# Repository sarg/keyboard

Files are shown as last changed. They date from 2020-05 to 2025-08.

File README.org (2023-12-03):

My journey to this keyboard began with a birthday gift. I got a Microsoft Sculpt Comfort keyboard and finally learned the proper 10 finger typing method. Then I got into spacemacs and fell in love with the idea of using space as a leader key. And as a newly adopted emacs user I began using Ctrl and Alt heavily. Reaching for control required unnatural wrist movement and I got to know that the solution is to remap Caps as Ctrl. I was living with this hack for a while until I learned a better idea - to remap LCtrl with LAlt. That's when I started looking for the keyboards with shorter space, so that LCtrl is easily reachable by the left thumb. Eventually I stumbled upon a world of DIY keyboards and started dreaming about ergodox. It was too pricey and had not the ideal layout so I decided to build my own keeb.
I had a rough understanding of what I'm aiming for - a handwired split keyboard with a orthogonal layout and a thumb cluster where I could leave hands on the home row indefinetely. So I started by ordering the parts - switches and caps.
When the switches came I immediately started to design a layout for my keyboard which fits my hands the perfectly.

* Parts

| Name                |   Qty | Price, $ |
|---------------------+-------+----------|
| Diodes 1n4148       |   100 |     0.78 |
| Keys Gateron Brown  |    50 |    21.00 |
| Keys Gateron Red    |    10 |          |
| Keys Gateron Other  |     5 |          |
| Keycaps PBT DSA     |    65 |    17.90 |
| Atmega32u4          |     1 |     2.88 |
| Atmega32u4          |     1 |     3.22 |
| Wires               | 1 set |      2.2 |
| 3.5mm plug          |     2 |      0.9 |
| 3.5mm cable         |     1 |     1.58 |
| encoder             |     5 |     1.78 |
| knob                |    10 |     1.40 |
| petg filament 1kg   |     1 |       30 |
| petg leftover       |       |      -24 |
| soldering paste     |     1 |     2.29 |
| soldering wire 100g |     1 |       11 |
| soldering wire left |       |      -10 |
|---------------------+-------+----------|
| tent screws         |     8 |          |
| plastidip           |     1 |          |
| tent fixing nuts    |     4 |          |
| tent nuts M5        |     4 |          |
|---------------------+-------+----------|
| total               |       |    62.93 |
#+TBLFM: @>$3=vsum(@I..@II)

* Layout
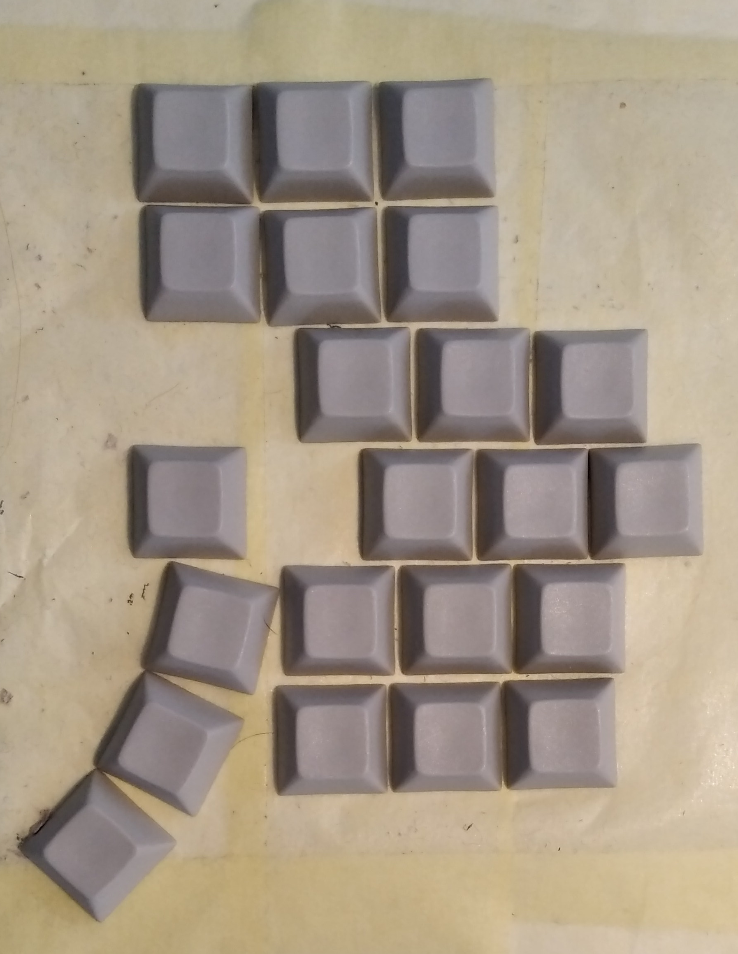
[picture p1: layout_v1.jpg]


- To find a best layout for my hands I've put several stripes of masking tape glue side up on a sheet of paper.
- Then I've adjusted columns to my liking and measured the offsets.
- I have Gateron switches which are Cherry-MX compatible. So the hole size is 14x14 mm and distance between holes should be 5 mm.
- Thumb cluster is parameterized in polar coordinates.

* Case design
** v1
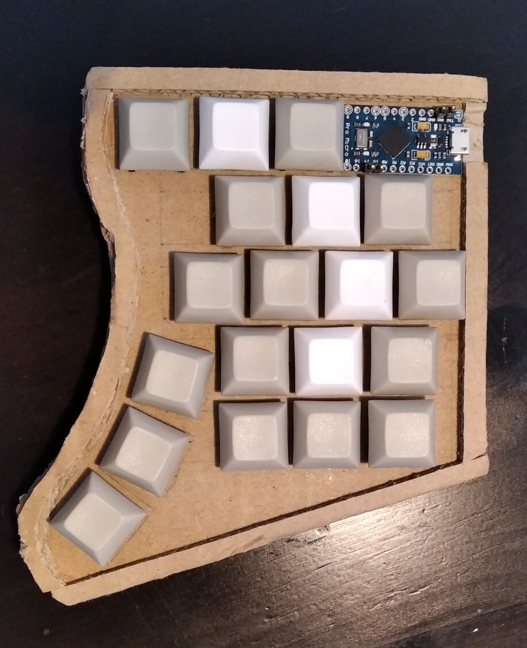
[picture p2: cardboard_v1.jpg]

** v2
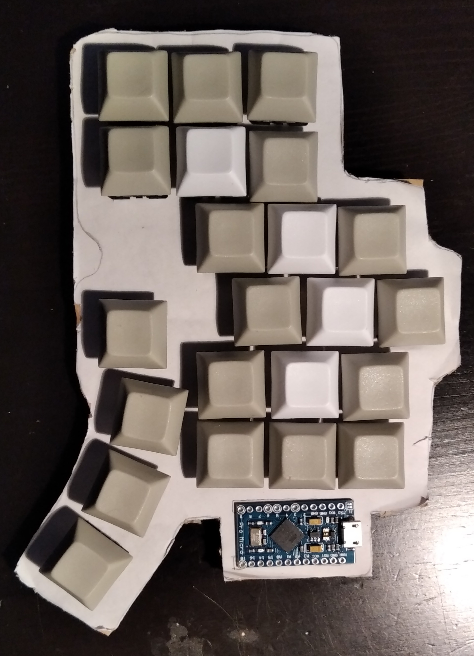
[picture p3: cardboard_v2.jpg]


** manufacturing
I'm going to choose one of the options.
1. PCB only
   jlcpcb, x5 ~ 27$ + 11$ shipping
2. *3d printed*
3. laser cutted
   price estimation:
   - $5.14 x 2 + $9 (fixed, handling) = $19.28 (ponoko)
   - €8.20 x 2 + shipping (formulor.de), no 1.5mm material

3d printing it is. Next time I'll try PCBs. It seems that you can use PCB as top plate and the manufacturer could mill holes of any shape.
* 3d printing
https://thomasbaart.nl/2019/04/07/cheat-sheet-custom-keyboard-mounting-styles/

- [[https://all3dp.com/1/3d-printing-support-structures/][need of support structures for overhang]]
- tolerances for an easy assembly
- choosing proper thickness to ensure integrity

Requirements.
1. switch should be firmly attached to the keyboard
   switch is designed to be mounted on a panel 1.5 mm thick and soldered onto PCB
   you can select one of those options - pcb+panel, panel only, pcb only

   produces: mounting place

2. switch should be positioned under the finger and easily accessible without much finger movement
   there are few ergonomic layouts that minimize finger movement. Just take one and adapt it to your hands

   2.1 keycaps are wider than the switch body. there should be minimal distance between keycaps so that they don't touch
   ortholinear + thumb cluster shaped as an arc

   produces: layout

3. mounting plate should be sturdy enough to not bend when typing

   produces: plate thickness

4. switches should be wired to the controller
   pcb or handwiring. Both need some vertical space
   something that elevates the plate needs to be implemented:
   - pins
   - another plate

   produces: wiring space

5. controller should have some place

   produces: controller location

6. underside of the keyboard should be protected
   pcb or handwiring should be protected from water spills and mechanical damage

   produces: bottom plate

7. optional: halves of a split keyboard should communicate

   produces: cable between halves, connectors

9. optional: tilt/tent

   produces: tent brackets

from handbook of 3d printing
make wall thickness proportional to nozzle width
add fillets everywhere
<45 degree overhang doesn't require support

** first print
For first print I've prepare a single row of 5 keys where each hole has size $14+i*0.1, i in [-2..2]$. I've found 14-0.2 the best. Then I've prepared small test case where I've mounted all the different types of switches I have. I had to redesign promicro mount after the print as the board wasn't fitting nicely.

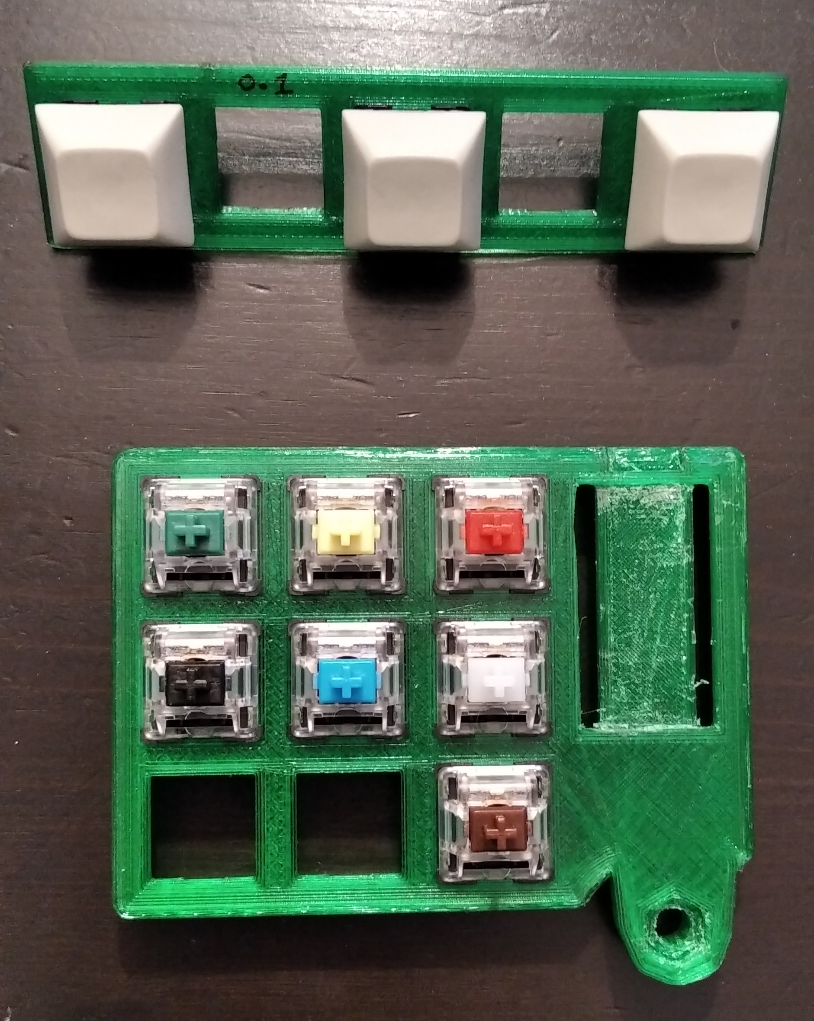
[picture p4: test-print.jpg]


* Hand-wiring
[[https://deskthority.net/viewtopic.php?f=7&t=6050&start=][BrownFox step by step - deskthority]]

The keyboard has 23 keys per hand - 3 rows of 6 columns and the fourth row of 4 thumb keys and an encoder button. It fits in a 4x6 matrix and requires =4+6=10= pins. Encoder takes 2 pins and serial connection takes another 1. In total: 10 pins for keys + 2 for encoder + 1 for serial + GND + VCC = 15 pins.

Some pins has extra functions and they have to be used last.

* Firmware
Consult [[https://beta.docs.qmk.fm/developing-qmk/c-development/hardware_keyboard_guidelines][documentation]].

Create new template with =./util/new_keyboard.sh=

#+BEGIN_SRC sh :dir firmware :results output :exports both
tree --noreport
#+END_SRC

#+RESULTS:
#+begin_example
.
|-- config.h
|-- keymaps
|   `-- default
|       |-- config.h
|       |-- keymap.c
|       `-- readme.md
|-- rules.mk
|-- sarg.c
`-- sarg.h
#+end_example

Let's go file by file to find minimal set of tweaks:

** =config.h=
#+BEGIN_SRC c
#define MATRIX_ROWS 8
#define MATRIX_COLS 6
/*
quantum/split_common/matrix.c presumes that kbd is split evenly by rows

#define ROWS_PER_HAND (MATRIX_ROWS / 2)
*/

// pinout http://i.imgur.com/wMNx2u6.png
#define MATRIX_ROW_PINS { D0, D5 }
#define MATRIX_COL_PINS { F1, F0, B0 }

#define DIODE_DIRECTION COL2ROW

#define SOFT_SERIAL_PIN D0  // or D1, D2, D3, E6
#+END_SRC

** =info.json=
Can be skipped, used in QMK web configurator.
** =rules.mk=
#+BEGIN_EXAMPLE
BOOTLOADER = caterina
SPLIT_KEYBOARD = yes
#+END_EXAMPLE
** =sarg.c=
Could be left as is.
** =sarg.h=
Here you define a macro that returns array of arrays with your layout.
#+INCLUDE: "./firmware/sarg.h" :lines "21-45" src c
** =keymaps/default/keymap.c=
Define layout in =keymaps= array.

* First compilation.
#+BEGIN_SRC sh
bin/qmk compile -kb sarg -km default
#+END_SRC

#+BEGIN_EXAMPLE
...
Checking file size of sarg_default.hex                                                              [OK]
 * The firmware size is fine - 23964/28672 (83%, 4708 bytes free)
#+END_EXAMPLE

* TODO link

Nicinabox has a [very nice and detailed guide](https://github.com/nicinabox/lets-split-guide) for the Let's Split keyboard, that covers most everything you need to know, including troubleshooting information.
* GUIX
#+BEGIN_SRC sh
guix time-machine -C channels.scm -- environment --pure -m manifest.scm
python3 -m venv pyvenv
source pyvenv/bin/activate
pip3 install -U qmk

make firmware
make flash
#+END_SRC
* flashing qmk-dfu
 1. build avrisp2 firmware from [[https://github.com/abcminiuser/lufa/tree/7a3b523c6473f9f6e0a7696f8ce66ee76119b21c/Projects/AVRISP-MKII][lufa]]
    #+begin_src sh
make -C Projects/AVRISP-MKII/ MCU=atmega32u4 BOARD=LEONARDO F_CPU=16000000
    #+end_src
 2. Flash avrisp2 firmware on promicro using avrdude
    #+begin_src sh
 while read i; do if [ "$i" = ttyACM0 ]; then break; fi; done \
    < <(inotifywait  -e create,open --format '%f' --quiet /dev --monitor)

 echo "Found device... flashing"
 avrdude  -patmega32u4 -c avr109 -P/dev/ttyACM0 -U flash:w:$1:i
    #+end_src
   #+begin_src sh
    sh flash.sh Projects/AVRISP-MKII/AVRISP-MKII.hex
   #+end_src
 3. Solder 6 wires for ISP programming
    #+begin_example
[ProMicro as AVRISP-mkII] <==> [Target ProMicro (or other AVR)]
GND <--> GND
VCC <--> VCC
PF4 <--> RST
PB1 <--> PB1 (SCK)
PB3 <--> PB3 (MISO)
PB2 <--> PB2 (MOSI)
    #+end_example
 4. Flash QMK firmware with bootloader (production)
    #+begin_src sh
 avrdude -p atmega32u4 -c avrisp2 -v -e -U lfuse:w:0x5E:m -U hfuse:w:0x99:m -U efuse:w:0xF3:m
 avrdude -p atmega32u4 -c avrisp2 -v -e -U flash:w:sarg_default_production.hex
    #+end_src
    Fuses are not magical. These basically set clock source, bootloader size and
    enable some features of the chip. Sure the values should be chosen carefully, for that consult the official datasheet for the controller. See also:
    https://rfong.github.io/rflog/2021/09/29/avr/
    https://docs.qmk.fm/#/isp_flashing_guide?id=flashing-the-bootloader
    https://www.engbedded.com/fusecalc/
 5. Repeat for the second ProMicro. Now that it has the dfu programmer, flash it this way
    #+begin_src
 dfu-programmer atmega32u4 erase
 dfu-programmer atmega32u4 flash AVRISP-MKII.hex
    #+end_src
 6. From now on to flash the keyboard, press the QK_BOOT key (see layout) and it will reboot to bootloader.

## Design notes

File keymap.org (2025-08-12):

* base
** left
#+name: l0
| ESC  | Q   | W         | E         | R         | T           |
| TAB  | A   | LALT_T(S) | LCTL_T(D) | LSFT_T(F) | G           |
| MINS | Z   | X         | C         | V         | B           |
| XXX  | ENT | MYCM      | LALT      | MO(1)     | LGUI_T(ENT) |
** right
#+name: r0
| Y           | U         | I         | O         | P    | BSPC |
| H           | RSFT_T(J) | RCTL_T(K) | RALT_T(L) | SCLN | QUOT |
| N           | M         | COMM      | DOT       | SLSH | BSLS |
| RALT_T(SPC) | MO(2)     | RALT      | RGUI      | ENT  | XXX  |
** encoders
#+name: e0
| PGUP | PGDN  |
| UP   | DOWN  |
* digits
** left
#+name: l1
| GRV | 1       |  2 | 3     | 4    |  5 |
|     |         |    | PGUP  | PGDN |    |
| F1  | F2      | F3 | F4    | F5   | F6 |
| XXX | QK_BOOT |    | TO(3) |      |    |
** right
#+name: r1
| 6    | 7    | 8  | 9    | 0    | MINS |
| LEFT | DOWN | UP | RGHT |      |      |
| F7   | F8   | F9 | F10  | F11  | F12  |
| RSFT | LGUI |    |      | MPLY | XXX  |
** encoders
#+name: e1
| VOLD | VOLU |
| VOLD | VOLU |
* symbols
** left
#+name: l2
| TILD | EXLM | AT | HASH | DLR | PERC |
|      |      |    |      |     |      |
|      |      |    |      |     |      |
| XXX  |      |    |      |     | LSFT |
** right
#+name: r2
| CIRC | AMPR | LPRN | RPRN | ASTR |     |
| MINS | EQL  | LBRC | RBRC |      |     |
| UNDS | PLUS | LCBR | RCBR |      |     |
|      |      |      |      |      | XXX |
** encoders
#+name: e2
| MEDIA_PREV_TRACK | MEDIA_NEXT_TRACK |
| UP               | DOWN             |
* gaming
** left
#+name: l3
| ESC   | 7 | 8    | 1    |    2 |   3 |
| GRV   | 9 | LEFT | UP   | RGHT |   4 |
| TO(0) | 0 | Q    | DOWN |    6 |   5 |
| XXX   |   | ENT  | TRNS |    C | SPC |
** right
#+name: r3
|   |   |   |   |   |     |
|   |   |   |   |   |     |
|   |   |   |   |   |     |
|   |   |   |   |   | XXX |
** encoders
#+name: e3
|   |   |
|   |   |
* keymap.json
#+name: helper
#+begin_src elisp :results none
(defun qmk/keyname (k)
  (let* ((m (and (stringp k)
                 (s-match (rx (group (+? anychar)) "("
                              (group (+ anychar) ")"))
                          k)))
         (fn (and m (nth 1 m)))
         (arg (and m (nth 2 m)))
         (fn-as-is (member fn '("MO" "TO"))))

    (cond
     ((numberp k) (format "KC_%d" k))
     ((string-empty-p k) "KC_NO")
     ((string-equal "XXX" k) nil)
     (fn-as-is k)
     (fn (concat fn "(KC_" arg))
     ((s-match "^.._" k) k)
     (t (concat "KC_" k)))))
#+end_src

#+name: layer
#+begin_src elisp :var l=l0 :var r=r0
(->>
 (-zip-with #'append l r)
 (-flatten)
 (-map #'qmk/keyname)
 (-filter #'identity)
 (-map (lambda (k) (format "%S" k)))
 (s-join ",\n"))
#+end_src

#+name: encoder
#+begin_src elisp :var e=e0
(s-join
 ", "
 (-map
  (lambda (enc)
    (apply #'format "{\"ccw\": %S, \"cw\": %S}"
           (-map #'qmk/keyname enc)))
  e))
#+end_src

#+begin_src js :tangle firmware/keymaps/default/keymap.json :noweb yes
{
  "version": 1,
  "notes": "",
  "documentation": "generated by org-mode",
  "author": "",
  "keyboard": "emajesty/eiri",
  "keymap": "keymap",
  "layout": "LAYOUT",
  "encoders": [
      [<<encoder(e0)>>],
      [<<encoder(e1)>>],
      [<<encoder(e2)>>],
      [<<encoder(e3)>>]
  ],
  "layers": [
    [
      <<layer(l0,r0)>>
    ],
    [
      <<layer(l1,r1)>>
    ],
    [
      <<layer(l2,r2)>>
    ],
    [
      <<layer(l3,r3)>>
    ]
  ]
}
#+end_src

#+name: cencoder
#+begin_src elisp :var e=e0 :var l=0
(s-join
 ",\n"
 (-map-indexed
  (lambda (idx enc)
    (format "{ %d, %d, false, %s, NO },\n{ %d, %d, true, %s, NO }"
            l idx (qmk/keyname (nth 0 enc))
            l idx (qmk/keyname (nth 1 enc))))
  e))
#+end_src

#+name: clayer
#+begin_src elisp :var l=l0 :var r=r0 :var i=0
(concat
(s-join ",\n"
        (-filter #'identity
        (-flatten
         (-map-indexed
          (lambda (row keys)
            (-map-indexed
             (lambda (col key)
               (when-let ((skey (qmk/keyname key)))
                  (format "{ %d, %d, %d, %s, NO }" i row col skey)))
             keys))
          (append l (-map #'reverse r)))))))
#+end_src

#+begin_src c :tangle write_eeprom/keymap.h :noweb yes
const KEY keys[] = {
  <<clayer(l0, r0, 0)>>,
  <<clayer(l1, r1, 1)>>,
  <<clayer(l2, r2, 2)>>,
  <<clayer(l3, r3, 3)>>
};

const ENCODER encoders[] = {
  <<cencoder(e0, 0)>>,
  <<cencoder(e1, 1)>>,
  <<cencoder(e2, 2)>>,
  <<cencoder(e3, 3)>>
};
#+end_src

# Local Variables:
# compile-command: "just eeprom"
# End:

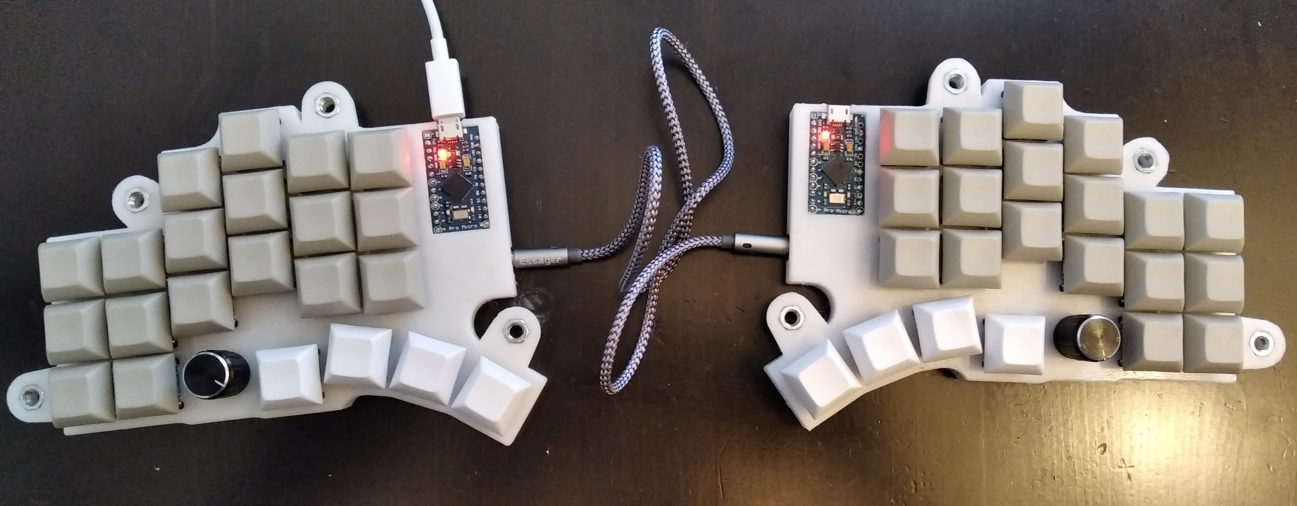
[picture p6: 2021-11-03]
photos/keyb.jpg

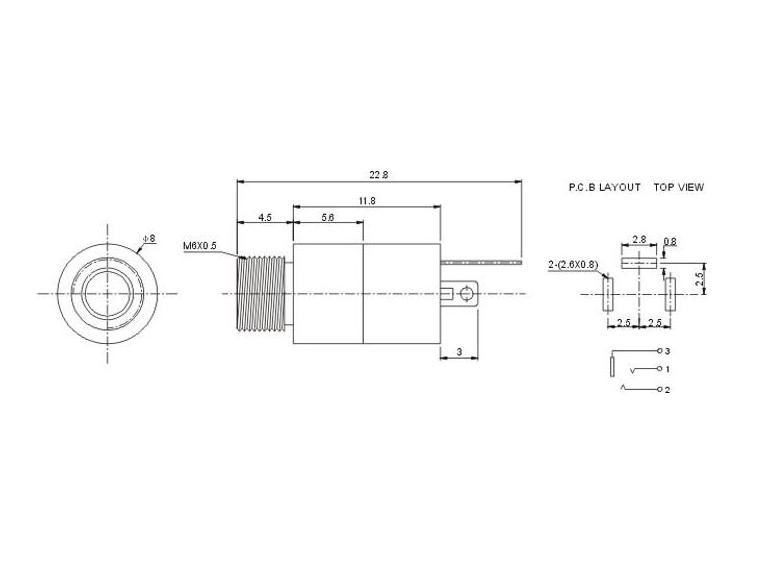
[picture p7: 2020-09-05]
pj392.jpg

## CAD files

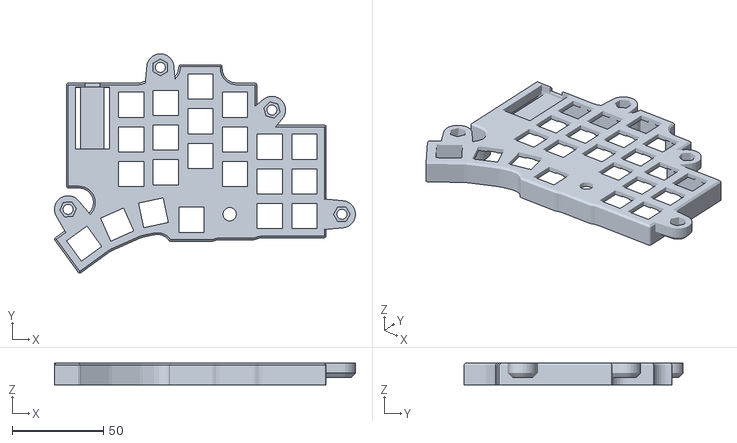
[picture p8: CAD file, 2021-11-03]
right.stl
165.0 x 120.3 x 12.0

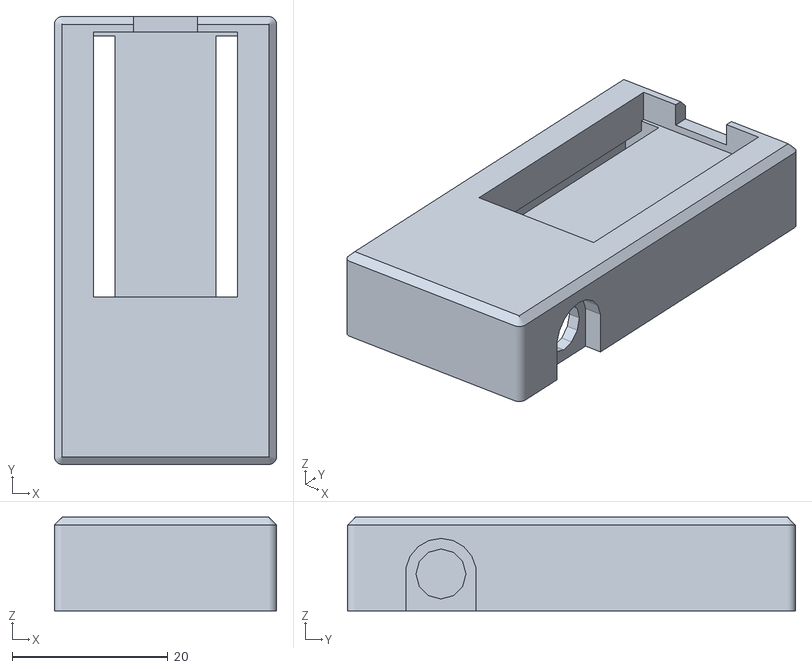
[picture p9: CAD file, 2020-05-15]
test-ic.stl
28.5 x 57.5 x 12.0

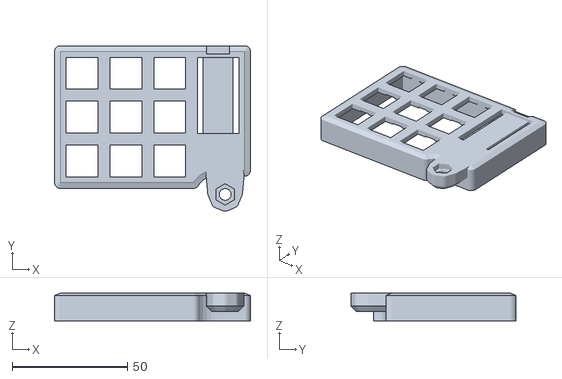
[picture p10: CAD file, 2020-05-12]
test-keyb.stl
84.9 x 71.7 x 12.0

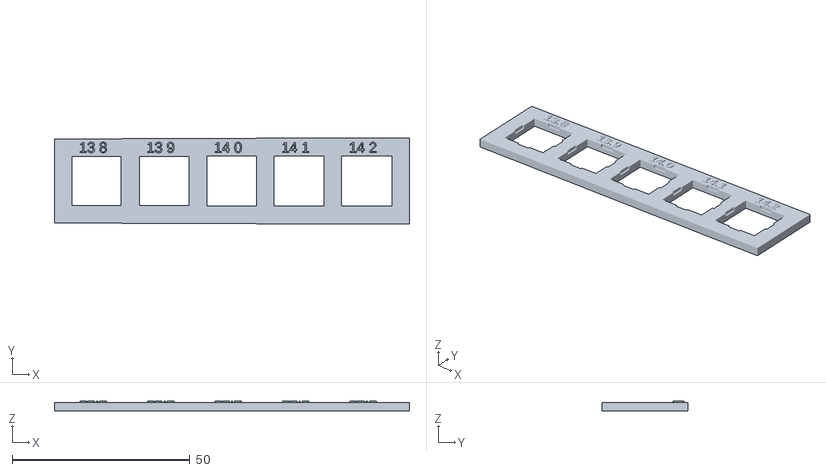
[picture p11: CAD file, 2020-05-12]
calibrate.stl
100.0 x 24.2 x 2.90

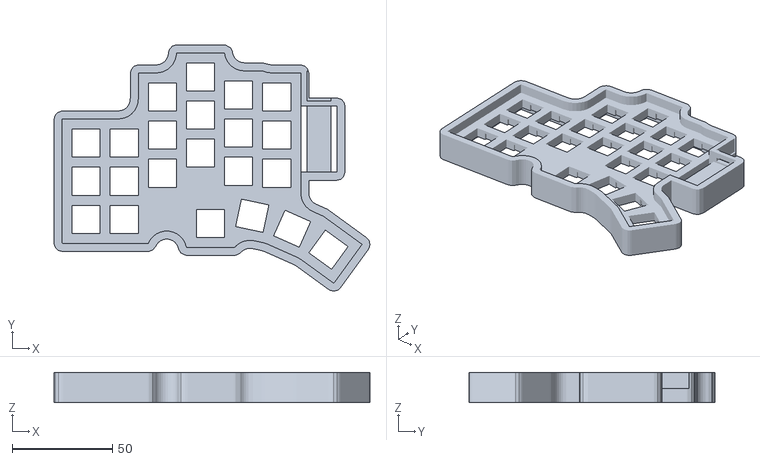
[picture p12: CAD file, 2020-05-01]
keyb.stl
157.5 x 122.8 x 15.0

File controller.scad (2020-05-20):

ic_thickness = 1;
ic_size=[18,33];

usb_socket_height=2;
trrs_d=8;
trrs_w=10;

trrs_pos=[0, -ic_size[1]/2-trrs_d/2-trrs_w/2,(thickness+deepening)/2-0.5];

function get_ic_size() = ic_size;

module board() {
    square(size=ic_size, center=true);
}

module trrs_socket() {
    translate(trrs_pos) {
        translate([ic_size[0]/2+wall_thickness,0,0]) {
            rotate([0,90,0]) cylinder(h=4.5,d=6, $fn=50);

            translate([wall_thickness,0,0])
                rotate([0,90,0]) cylinder(h=2,d=8, $fn=50);

            translate([-11.8,0,0]) rotate([0,90,0])
                cylinder(h=11.8,d=8, $fn=50);

            translate([-11.8-3,0])
                cube([3,2,1]);
        }
    }
}

module controller_perimeter() {
    union() {
        offset(delta=2) board();
        offset(delta=2)
        translate(trrs_pos)
            square([ic_size[0], trrs_w], center=true);
    }
}

module cutout() {
    union() {
        // submerge controller in the plate
        translate([0,0,thickness-ic_thickness])
            linear_extrude(height=ic_thickness+1)
            board();

        // space for IC pins
        linear_extrude(height=thickness)
            difference() {
                board();
                square(size=ic_size-[2.6*2, 0], center=true);
            }
    }
}

module promicro() {
    translate([0,0,-ic_thickness])
        linear_extrude(height=ic_thickness)
        board();

    translate([-4, ic_size[1]/2-4])
        cube([8,5,usb_socket_height]);
}

module controller() {
    difference() {
        linear_extrude(height=thickness)
            offset(delta=2) board();

        cutout();
    }

    if ($preview) {
        color("blue")
            translate([0,0,thickness]) promicro();

    }
}

promicro();

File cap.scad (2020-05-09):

module keycap() {
    translate([0,0,0.5]) {
        hull() {
            cube(size=[18,18,1], center=true);
            translate([0,0,7])
                cube(size=[12,12,1], center=true);
        }
    }
}

keycap();

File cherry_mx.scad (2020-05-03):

$fn=60;
/**
a cherry mx switch.

most of the measurements done with a caliper. some taken from
http://geekhack.org/index.php?topic=47744.0

This is just to illustrate and to drop in a a gross reference. It is mostly artistic apart from the steam and mounting plate dimensions
*/

// move the whole thing 3mm to give the empty space in usual keycaps.
// that is, the extra space inside a keycap female connector.
// i do that since i create all my keycaps with 0,0,0 being the internal base of the keycap
translate([0,0,4 +5.3 +0.82])
{

	//1. steam
	color("brown"){
		//1.1. l-r tab is 1.35mm
		translate([0,0,-3.62/2])
			cube([1.35,4.5,3.62], center=true);
		//1.2. f-b tab is 1.15mm. it has a smal notch that i will ignore.
		translate([0,0,-3.62/2])
			cube([4.5,1.15,3.62], center=true);
		//1.3. base. it has a chamfered top that i will ignore.
		translate([0,0,-5.62])
			cube([7.2,5.56,4], center=true);
	}
	// 2. top
	color("grey"){
		difference(){
			// make a trapezoid with the general shape (volume?) of the top
			hull(){
				translate([0,0,-4]) //distance from top of switch... some i measured 3.9 others 4.2... so leaving at 4
					cube([9.87,10.62,0.1], center=true);
				translate([0,0,-4 -5.2]) // bottom has a measured 5.3... so move 5.2 and use the 0.1 bellow
					cube([14.58,14.58,0.1], center=true);
			}

		// and subtract:
		// the front led. NOTE: totally off... measured by eye. just for astetics
		// adding just so there is a visual cue of the direction
			translate([0,-4.7,-6])
				cylinder(r=3/2, h=6, center=true);
			translate([0,-5.5,-6])
				cube([8,4,5], center=true);
		// the four corners
			// TODO waste of time? this is all for looks, you shouldn't invade any of that space anyway...
		}
	}

	// 3. bottom
	color("green")
		// 3.1 main body volume
		hull(){
				translate([0,0,-4 -5.3]) //steam + top
					cube([13.98,13.98,0.1], center=true);
				translate([0,0,-4 -5.3 -2.2]) //steam + top + straigth part
					cube([13.98,13.98,0.1], center=true);
				translate([0,0,-4 -5.3 -5.5]) //steam + top + bottom (measured 5.5)
					cube([12.74,13.6,0.1], center=true);
		}
		// 3.2 tabs
		// note: only measured the lenght, if they are slightly off-center, this will be all wrong :)
		color("black")
		difference(){
			translate([0,0,-4 -5.3 -0.82/2]) //steam + top
				cube([15.64,15.64,0.82], center=true);
			translate([0,0,-4 -5.3 -0.82/2  ]) // front-back cut
				cube([5.64,20,0.82 +2], center=true);
			translate([0,0,-4 -5.3 -0.82/2  ]) //side cut
				cube([20,11.64,0.82 +2], center=true);
		}

		// 3.3 tab (plate snap on). to use this mechanically, you have to take into account the bending (as it will move the bottom part slightly up...) just for gross reference here for now
		color("white"){
			// 3.3.1 top
			translate([0,0,-4 -5.3 -0.82/2  ]) // front-back cut
				cube([1.82,16.33,0.82], center=true);
			// 3.3.2 bottom
			difference(){
				hull(){
					translate([0,0,-4 -5.3 -0.82/2 -1.76  ]) // front-back cut
						cube([3.65,14,0.1], center=true);
					translate([0,0,-4 -5.3 -0.82/2 -2.2  ]) // front-back cut
						cube([3.65,14.74,0.1], center=true);
					translate([0,0,-4 -5.3 -0.82/2 -2.89  ]) // front-back cut
						cube([3.65,14,0.1], center=true);
				}
				translate([0,0,-4 -5.3 -0.82/2 -1.76   ]) // front-back cut
					cube([2.2,20,4], center=true);

			}
		}

		// 4. bottom guides
		// again, i'm assuming everything is centered...
		color("darkGreen"){
			// 4.1 cylinder
			translate([0,0,-4 -5.3 -5.5 -2/2]) //steam + top + bottom (measured 5.5)
				cylinder(r=3.85/2, h=2, center=true);
			translate([0,0,-4 -5.3 -5.5 -2 -1/2]) //steam + top + bottom (measured 5.5)
				cylinder(r2=3.85/2, r1=2.8/2, h=1, center=true);
			// 4.2 PCB pins
			translate([4.95,0,-4 -5.3 -5.5 -2/2]) //steam + top + bottom (measured 5.5)
				cylinder(r=1.6/2, h=2, center=true);
			translate([4.95,0,-4 -5.3 -5.5 -2 -1/2]) //steam + top + bottom (measured 5.5)
				cylinder(r2=1.6/2, r1=1/2, h=1, center=true);
			translate([-4.95,0,-4 -5.3 -5.5 -2/2]) //steam + top + bottom (measured 5.5)
				cylinder(r=1.6/2, h=2, center=true);
			translate([-4.95,0,-4 -5.3 -5.5 -2 -1/2]) //steam + top + bottom (measured 5.5)
				cylinder(r2=1.6/2, r1=1/2, h=1, center=true);
		}

		// 5. pins
		color("orange"){
			translate([-3.77,2.7,-4 -5.3 -5.5 -3.1/2]) //steam + top + bottom (measured 5.5)
				cube([.86, 0.2,3.1], center=true);
			translate([2.7,5.2,-4 -5.3 -5.5 -3.1/2]) //steam + top + bottom (measured 5.5)
				cube([.86, 0.2,3.1], center=true);
		}

}

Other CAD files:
left.stl
keyb.scad

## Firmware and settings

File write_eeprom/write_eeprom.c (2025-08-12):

#include <stdio.h> // printf
#include <wchar.h> // wchar_t
#include <hidapi.h>
#include <quantum_keycodes.h>
#include <modifiers.h>
#include <stdint.h>

typedef struct KEY {
  uint8_t layer;
  uint8_t row;
  uint8_t col;
  uint16_t keycode;
  bool diff;
} KEY;

typedef struct ENCODER {
  uint8_t layer;
  uint8_t idx;
  bool clockwise;
  uint16_t keycode;
  bool diff;
} ENCODER;

#define NO false
#include "keymap.h"

#define MAX_STR 255

int main(int argc, char* argv[])
{
    int res;
    bool diffmode = argc == 1;
    wchar_t wstr[MAX_STR];
    hid_device *handle;
    int i;

    // Initialize the hidapi library
    res = hid_init();

    // Declare variables for enumeration and specific device identification
    struct hid_device_info *devs, *cur_dev;

    handle = NULL; // Initialize handle to NULL
    devs = hid_enumerate(0, 0);

    if (!devs) {
        hid_exit();
        return 1;
    }

    cur_dev = devs;
    while (cur_dev) {
        if (cur_dev->usage_page == 0xff60 && cur_dev->usage == 0x61) {
            // Attempt to open the device using its path
            handle = hid_open_path(cur_dev->path);
            if (handle) {
                break;
            }
        }
        cur_dev = cur_dev->next;
    }

    // Free the enumeration list
    hid_free_enumeration(devs);

    // Check if a device was successfully opened
    if (!handle) {
        printf("Unable to open device\n");
        hid_exit();
        return 1;
    }

    // Read the Manufacturer String
    res = hid_get_manufacturer_string(handle, wstr, MAX_STR);
    printf("Manufacturer String: %ls\n", wstr);

    // Read the Product String
    res = hid_get_product_string(handle, wstr, MAX_STR);
    printf("Product String: %ls\n", wstr);

    for (int i=0; i<sizeof(keys)/sizeof(KEY); i++) {
        const KEY key = keys[i];
        if (diffmode && !key.diff) continue;

        unsigned char buf[7] = {
            0x0, 0x05, key.layer, key.row, key.col, key.keycode >> 8, key.keycode & 0xFF
        };

        for (size_t j = 0; j < sizeof(buf); j++) {
            printf("%02X ", buf[j]);
        }

        res = hid_write(handle, buf, sizeof(buf));
        hid_read(handle, buf, sizeof(buf)-1);

        printf(" -> ");
        for (size_t j = 0; j < sizeof(buf)-1; j++) {
            printf("%02X ", buf[j]);
        }
        printf("\n");
    }

    for (int i=0; i<sizeof(encoders)/sizeof(ENCODER); i++) {
        const ENCODER enc = encoders[i];
        if (diffmode && !enc.diff) continue;

        unsigned char buf[7] = {
            0x0, 0x15, enc.layer, enc.idx, enc.clockwise, enc.keycode >> 8, enc.keycode & 0xFF
        };

        for (size_t j = 0; j < sizeof(buf); j++) {
            printf("%02X ", buf[j]);
        }

        res = hid_write(handle, buf, sizeof(buf));
        hid_read(handle, buf, sizeof(buf)-1);

        printf(" -> ");
        for (size_t j = 0; j < sizeof(buf)-1; j++) {
            printf("%02X ", buf[j]);
        }
        printf("\n");
    }

    // Close the device
    hid_close(handle);

    // Finalize the hidapi library
    res = hid_exit();

    return 0;
}

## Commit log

2020-04-30 Init repo.
    [keyb.scad]
2020-04-30 Update design, export stl.
    [cap.scad, cherry_mx.scad, keyb.scad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]
2020-05-01 Update design.
    [keyb.scad, keyb.stl]
2020-05-03 Add ears for tent/tilt bolts.
    [controller.scad, keyb.scad]
2020-05-03 Fix cherry-mx warnings.
    [cherry_mx.scad]
2020-05-03 Trim the plate a little bit so it fits into the case.
    [controller.scad, keyb.scad]
2020-05-09 Convert to scad-clj.
    [cap.scad]
2020-05-12 Test boards.
    [calibrate.stl, test-keyb.stl, wow.stl]
2020-05-12 Test ic placement.
    [test-ic.stl]
2020-05-13 Prepare test-ic for print.
    [test-ic.stl]
2020-05-14 Fix test-ic after print.
    [test-ic.stl]
2020-05-15 Final adjustments.
    [test-ic.stl, wow.stl]
2020-05-16 Increase encoder hole a little.
    [wow.stl]
2020-05-20 Find out which pins to use.
    [controller.scad, wow.stl]
2020-09-04 Generate right half of the keyb.
    [left.stl, right.stl, wow.stl]
2020-09-07 Fix encoders and right layout.
2021-11-03 Add photos.
    [keyb.scad, left.stl, right.stl]
2025-08-10 switch to justfile, add envrc
2025-08-12 fix track switching keys
2025-08-12 remove vid/pid hardcode from eeprom tool
2025-08-13 set handedness pin
